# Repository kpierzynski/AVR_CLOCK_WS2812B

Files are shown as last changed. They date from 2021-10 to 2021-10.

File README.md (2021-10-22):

# WS2812B_AVR_CLOCK

#### Hello!
This is simple clock using WS2812B leds, AVR processor and clock crystal.
AVR uC is handling both leds with overclocked internal oscilator and RTC (only time without date) using Timer2 in async mode (AVR134).

Time can be set using UART by sending string in format: ssmmhh\n

Note: WSL - Windows Subsystem for Linux can run windows app, so in Makefile I'm using avrdude.exe to upload code to uC, but compile on linux. 

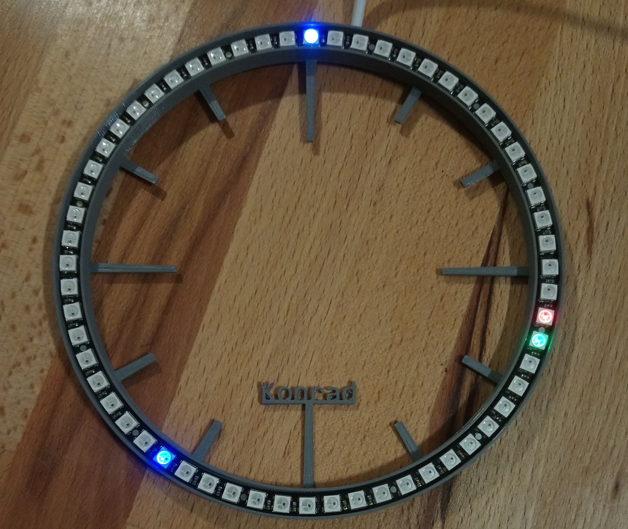
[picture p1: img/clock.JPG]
example_img


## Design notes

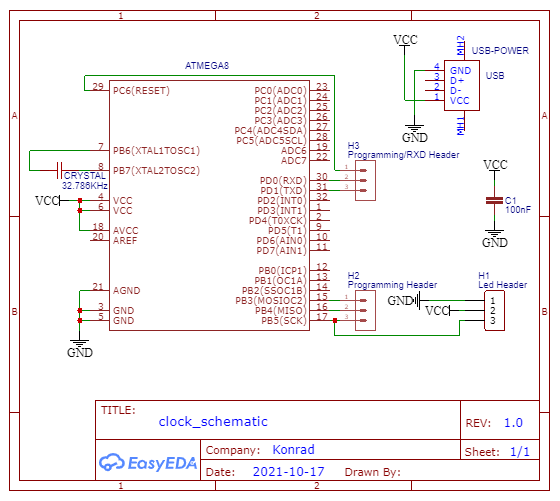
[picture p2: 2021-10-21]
pcb/schemat.png

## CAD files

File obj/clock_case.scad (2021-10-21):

base_th = 0.28*4;
wall_th = 0.28*6;
h = 6 + base_th;

D = 157+1+2;
d = 145-2;

$fn = 512;

name = "YourName";

sectors = [1,2,4,5,7,8,10,11];
big_sectors = [0,3,6,9];
guides = [ [60,big_sectors], [80,sectors] ];

module sector(h, d, a1, a2) {
    if (a2 - a1 > 180) {
        difference() {
            cylinder(h=h, d=d);
            translate([0,0,-0.5]) sector(h+1, d+1, a2-360, a1); 
        }
    } else {
        difference() {
            cylinder(h=h, d=d);
            rotate([0,0,a1]) translate([-d/2, -d/2, -0.5])
                cube([d, d/2, h+1]);
            rotate([0,0,a2]) translate([-d/2, 0, -0.5])
                cube([d, d/2, h+1]);
        }
    }
}   

module ring(D,d,th) {
    linear_extrude(height=th) difference() {
        circle(d=D);
        circle(d=d);
    }
}

module wall(D,h,th) {
    linear_extrude(height=h) difference() {
        circle(d=D);
        circle(d=D-th);
    }
}

for( guide = guides ) {
    difference() {
        union() {
            for( s = guide[1] ) 
                rotate([0,0,-2.5/2+s*30]) sector(base_th,d,0,2.5);
        }
        cylinder(d=guide[0]/100*d, h=base_th);
    }
}

translate([-60/100*d/2,0,base_th/2]) { 
    cube([1,30,base_th], center=true);
    translate([0,0,-base_th/2])
        rotate([0,0,-90])
            resize([30,0,0]) linear_extrude(height=base_th)
                text(name, valign="bottom", halign="center", size=7, font="consolas");
}

wall(D,h,wall_th);
wall(d,h,wall_th);

difference() {
    ring(D,d,base_th);
    rotate([0,0,-10]) sector(base_th, D, 0, 20);
}

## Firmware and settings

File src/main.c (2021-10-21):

#include <avr/io.h>
#include <util/delay.h>
#include <avr/interrupt.h>
#include <avr/sleep.h>

#define WS_PORT			PORTB
#define WS_DIR			DDRB
#define WS_PIN			(1<<PB5)

#define WHITE_LED_ON_12
#define BLINK_MM

#define BOUD			9600

#define RED			3
#define GREEN			2
#define BLUE			3

#define COLOR_SS		r
#define COLOR_MM		b
#define COLOR_HH		g

#define INTERRUPT		INT0
#define INTERRUPT_EDGE		ISC00
#define INTERRUPT_CONFIG	EICRA
#define INTERRUPT_MASK		EIMSK
#define INTERRUPT_VECT		INT0_vect
#define INTERRUPT_DDR		DDRD
#define INTERRUPT_PIN		(1<<PD2)
#define INTERRUPT_PORT		PORTD

#define RX_DDR			DDRD
#define	RX_PIN			(1<<PD0)

#define DEFAULT_SS		0
#define DEFAULT_MM		0
#define DEFAULT_HH		0

void ws281x_asm_send( void *data, uint16_t datlen, uint8_t pin );

void init_uart();
void uart_process_time();
void uart_rx();

void init_rtc();

//Note: ws leds accept green then red then blue values
typedef struct {
	uint8_t g;
	uint8_t r;
	uint8_t b;
} TRGB;

typedef struct {
	uint8_t ss;
	uint8_t mm;
	uint8_t hh;
} TTIME;

typedef struct {
	uint8_t pos;
	uint8_t buff[16];
} TRX;

//Note: global variables are reset to 0.
TRX rx;
TRGB leds[60];
TTIME time = {DEFAULT_SS,DEFAULT_MM,DEFAULT_HH};

int main() {
	//Overclock internal oscilator 224 to operate near 11.0592 MHz
	OSCCAL = 224;

	//Set INT and RXD pins to input
	RX_DDR &= ~RX_PIN;

	INTERRUPT_DDR &= ~INTERRUPT_PIN;
	//Pullup INT pin to high with internal resisitor
	INTERRUPT_PORT |= INTERRUPT_PIN;

	//Set INT0 trigger method to any logical change
	INTERRUPT_CONFIG |= (1<<INTERRUPT_EDGE);
	//Enable INT0 interrupt
	INTERRUPT_MASK |= (1<<INTERRUPT);

	//Inits
	init_uart();
	init_rtc();

	while(1) {
		//Make AVR sleepy
		sleep_mode();

		//Process uart rx
		uart_rx();

		//Write dummies to control register of Timer2
		TCCR2B |= (1<<CS22)|(1<<CS20);
		//Wait for busy flags to process
		while(ASSR & ((1 << TCN2UB) | (1 << OCR2AUB) | (1 << TCR2AUB)));

		//Process ws leds
		//Clear leds buffer
		for( uint8_t i = 0; i < 60*3; i++ ) *((uint8_t*)leds + i) = 0;

		//Set led on position time.ss
		leds[time.ss].COLOR_SS = RED;

		//Set led on position time.mm
		//Blink mm led
	#ifdef BLINK_MM
		//Note: last bit (2^0 = 1) define if number is odd or even. Much better way than %2 == 0
		if( time.ss & 1 ) {
			leds[time.mm].COLOR_MM = BLUE;
		}
	#else
		leds[time.mm].COLOR_MM = BLUE;
	#endif
		//Process hour led
		//5*time.hh maps hour range from 0-12 to 0-60
		//Then we add minutes dividev by 5 to get smooth hour's led stepping.
		//And make sure that we not exited 60 led range
		leds[ ( 5*time.hh + time.mm/12 ) % 60 ].COLOR_HH = GREEN;

		//Turn on white led towards upside
		//If led 0 is turn off, then set it to white
		//If there is any color, then skip
	#ifdef WHITE_LED_ON_12
		if( !leds[0].r && !leds[0].g && !leds[0].b ) {
			leds[0].r = RED; leds[0].g = GREEN; leds[0].b = BLUE;
		}
	#endif

		//Send led buffer to leds on WS_PIN
		ws281x_asm_send( leds, 60, WS_PIN );

	}
	return 0;
}

void init_uart() {
	#define __UBRR__ F_CPU/16/BOUD-1

	//Set uart to 9600
	uint16_t ubrr = __UBRR__;
	UBRR0H = (uint8_t)(ubrr>>8);
	UBRR0L = (uint8_t)(ubrr);

	//Set 1bit stop and enable receiver
	UCSR0B = (1<<RXEN0);
	UCSR0C = (1<<UCSZ00)|(1<<UCSZ01);
}

void init_rtc() {
	//Wait some time for stabilize clocks
	_delay_ms(100);

	//Turn off Timer2 in time of init
	TIMSK2 &= ~( (1 << OCIE2A) | (1<<OCIE2B) | (1 << TOIE2) );
	//Turn on async mode
	ASSR |= (1<<AS2);
	//Reset timer
	TCNT2 = 0;

	//Set 128 prescaler: 32.768 / 128 = 1sec precisely
	TCCR2B |= (1<<CS22)|(1<<CS20);

	//Wait for busy flags to start operate
	while(ASSR & ((1 << TCN2UB) | (1 << OCR2AUB) | (1 << TCR2AUB)));

	//Enable Timer2 overflow interrupt
	TIMSK2 |= (1<<TOIE2);

	//Turn on global interrupts
	sei();

	//Setup sleep mode on PowerSave. (On PowerSave mode Timer2 can operate in async mode)
	set_sleep_mode(SLEEP_MODE_PWR_SAVE);

	//Enable sleep mode
	sleep_enable();
}

ISR(TIMER2_OVF_vect) {
	//Handle passing one second

	if( ++time.ss == 60 ) {
		time.ss = 0;
		if( ++time.mm == 60 ) {
			time.mm = 0;
			if( ++time.hh == 24 ) {
				time.hh = 0;
			}
		}
	}
}

void uart_rx() {
	//Check if there is any data to receive in UDR register
	if( !(UCSR0A & (1<<RXC0) ) ) {
		//If not, return
		return;
	} else {
		//If yes, process time
		//uart_process_time();
		register uint8_t udr = UDR0;
		rx.buff[rx.pos++] = udr;

		//Process rx buffer data if enter was pressed
		if( udr == '\r' || udr == '\n' ) {
			uart_process_time();
			rx.pos = 0;
		}
	}
}

void uart_process_time() {
	//Time from uart comes in format: ssmmhh[enter]
	//Without : or spaces

	//If in buffer is not 7 symbols (ssmmhh\n), then return because of error
	if( rx.pos != 7 ) return;

	uint8_t t[3] = {0,0,0};

	//Convert ascii numbers to numbers
	//Note: ascii (for example) 15 is two bytes: '1' and '5'. '1' has value of (48 + 1 = 49) , '5' is (48 + 5 = 53). So to get number from ascii we have to subtract 48.
	for( uint8_t i = 0; i < 3; i++ ) {
		for( uint8_t p = 0; p < 2; p++ ) {
			t[i] += ( ( p == 0 ) ? 10 : 1 ) * ( rx.buff[2*i+p] - 48 );
		}
	}

	//Set new time
	time.hh = t[2];
	time.mm = t[1];
	time.ss = t[0];
}

ISR( INTERRUPT_VECT ) {
	//Dummy interrupt routine to wake up core when data is sent to uart rx
}

//Function to send buffer to ws leds.
void ws281x_asm_send( void *data, uint16_t datlen, uint8_t pin ) {

	uint8_t databyte=0, cnt, pinLO=~pin;
	WS_DIR |= pin;
	datlen *= 3;

#if F_CPU == 11059200

	asm volatile(
	"		lds		%[cnt],%[ws_port]	\n\t"			
	"		or		%[pinHI],%[cnt]		\n\t"	
	"		and		%[pinLO],%[cnt]		\n\t"		
	"mPTL%=:subi	%A6,1					\n\t"			
	"		sbci	%B6,0				\n\t"			
	"		brcs	exit%=				\n\t"			
	"		ld		%[databyte],X+		\n\t"			
	"		ldi		%[cnt],8			\n\t"		

	"oPTL%=:sts		%[ws_port],	%[pinHI]		\n\t"		
			"		nop				\n\t"	

	"		lsl		%[databyte]			\n\t"			
	"		brcs	.+2					\n\t"			
	"		sts		%[ws_port],	%[pinLO]\n\t"			
	"		nop						\n\t"		

	"		dec		%[cnt]				\n\t"		
	"		sts		%[ws_port],	%[pinLO]\n\t"			
	"		breq	mPTL%=				\n\t"			
													

	"		rjmp	oPTL%=				\n\t"			
	"exit%=:							\n\t"		
	:	[cnt]"=&d" (cnt)
	:	[databyte]"r" (databyte), [ws_port]"M" (_SFR_MEM_ADDR(WS_PORT)), [pinHI]"r" (pin), 
		[pinLO]"r" (pinLO), [data]"x" (data), [datlen]"r" (datlen)
	);

#endif

}
